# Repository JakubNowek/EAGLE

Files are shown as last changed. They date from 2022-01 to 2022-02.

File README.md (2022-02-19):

<br />
<div align="center">
  <h2 align="center">Electronics in Automation</h3>

  <p align="center">
    7-Segment Display Clock Project
    <br />
    <br />
    <a href="https://github.com/JakubNowek/EAGLE/issues">Report Bug</a>
    ·
    <a href="https://github.com/JakubNowek/EAGLE/issues">Request Feature</a>
  </p>
</div>

<!-- TABLE OF CONTENTS -->
<details>
  <summary>Table of Contents</summary>
  <ol>
    <li>
      <a href="#about-the-project">About The Project</a>
    </li>
    <li><a href="#finished-project">Finished Project</a>
    </li>
    <li><a href="#pcb-layout">PCB layout</a></li>
    <li><a href="#arduino-code">Arduino Code</a></li>
    <li><a href="#bill-of-materials">Bill of materials</a></li>
  </ol>
</details>

## About the Project
The ESP-01s module connects to NTP server and retrives information about the current date from it. Next data is forwarded towards Arduino Pro-Mini which extracts the time in hours, minutes and seconds and sends them towards 7-segments display through shift register.
Everything is powered up by a 7.5-25V power supply, the power of which is reduced to 5V by a voltage stabilizer.

## Finished Project


## PCB layout
Layout was auto generated using Altium Designer.
pcb layout

## Arduino Code
Used code for ESP module and Pro-Mini board can be found [here](projects/Serial_NTP_clock/ESP8266_with_NTP_code.ino) and [here](projects/Serial_NTP_clock/Pro_mini_code.ino).

## Bill of materials
| Qty | Value | Device |
|-----|---|---|
| 2 | | 7SEG-CA |
| 6 | | BC556A-PNP-TO92-EBC |
| 2 | 0.1u | C-EU025-025X050 |
| 6 | 100 | R-EU_0414/15 |
| 1 | 10u | C-EU025-025X050 |
| 10  | 220 | R-EU_0414/15 |
| 1 | 2k2 | R-EU_0414/15 |
| 2 | 470u/25V | CPOL-EUE5-8.5 |
| 1 | 74HC595N | 74HC595N |
| 1 | 7805T | 7805T |
| 1 | DCJ0202 | DCJ0202 |
| 1 | ESP-01 | ESP-01 |
| 1 | LD117AV | LD117AV |
| 1 | LDQ-M3604RI | LDQ-M3604RI |
| 1 | PRO-MINI | PRO-MINI |

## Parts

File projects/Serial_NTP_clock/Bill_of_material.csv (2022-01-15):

Qty | Value | Device | Package | Parts | Description | AVAILABILITY | DESCRIPTION | MF | MP | MPN | OC_FARNELL | OC_NEWARK | PACKAGE | POPULARITY | PRICE | SPICEPREFIX
2 |  | 7SEG-CA | 7SEG-13 | D1, D2 | 7-segment DISPLAY |  |  |  |  |  |  |  |  | 5
6 |  | BC556A-PNP-TO92-EBC | TO92-EBC | T1, T2, T3, T4, T5, T6 | PNP Transistror |  |  |  |  |  |  |  |  | 0
2 | 0.1u | C-EU025-025X050 | C025-025X050 | C3, C5 | CAPACITOR, European symbol |  |  |  |  |  |  |  |  | 65 |  | C
6 | 100 | R-EU_0414/15 | 0414/15 | R4, R5, R6, R7, R8, R9 | RESISTOR, European symbol |  |  |  |  |  |  |  |  | 0 |  | R
1 | 10u | C-EU025-025X050 | C025-025X050 | C4 | CAPACITOR, European symbol |  |  |  |  |  |  |  |  | 65 |  | C
10 | 220 | R-EU_0414/15 | 0414/15 | R1, R3, R10, R11, R12, R13, R14, R15, R16, R17 | RESISTOR, European symbol |  |  |  |  |  |  |  |  | 0 |  | R
1 | 2k2 | R-EU_0414/15 | 0414/15 | R2 | RESISTOR, European symbol |  |  |  |  |  |  |  |  | 0 |  | R
2 | 470u/25V | CPOL-EUE5-8.5 | E5-8,5 | C1, C2 | POLARIZED CAPACITOR, European symbol |  |  |  |  |  |  |  |  | 0 |  | C
1 | 74HC595N | 74HC595N | DIL16 | IC1 | 8-bit SHIFT REGISTER, output latch |  |  |  |  |  |  |  |  | 0
1 | 7805T | 7805T | TO220H | IC2 | Positive VOLTAGE REGULATOR
1 | DCJ0202 | DCJ0202 | DCJ0202 | J1 | DC POWER JACK |  |  |  |  |  | unknown | unknown |  | 17
1 | ESP-01 | ESP-01 | ESP-01 | ESP1 | Check prices | Not in stock | ESP-01M ESP8266 DIP Adapter series Transceiver | 802.11 b/g/n (Wi-Fi, WiFi, WLAN) Evaluation Board | AI-Thinker | ESP-01 |  |  |  | Non-Standard AI-Thinker |  | None
1 | LD117AV | LD117AV | TO220L1 | IC3 | Low drop fixed and adjustable positive voltage regulators 1 A |  |  |  |  |  |  |  |  | 0
1 | LDQ-M3604RI | LDQ-M3604RI | LDQ-M3604RI | LED1 | Check prices | In Stock | Display, Seven Segment, 9.2MM, Red | Lumex | LDQ-M3604RI |  |  |  | None |  | None
1 | PRO-MINI | PRO-MINI | PRO-MINI | U$1 | Arduion Pro Mini Clone V1.0

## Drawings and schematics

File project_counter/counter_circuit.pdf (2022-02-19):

A

A

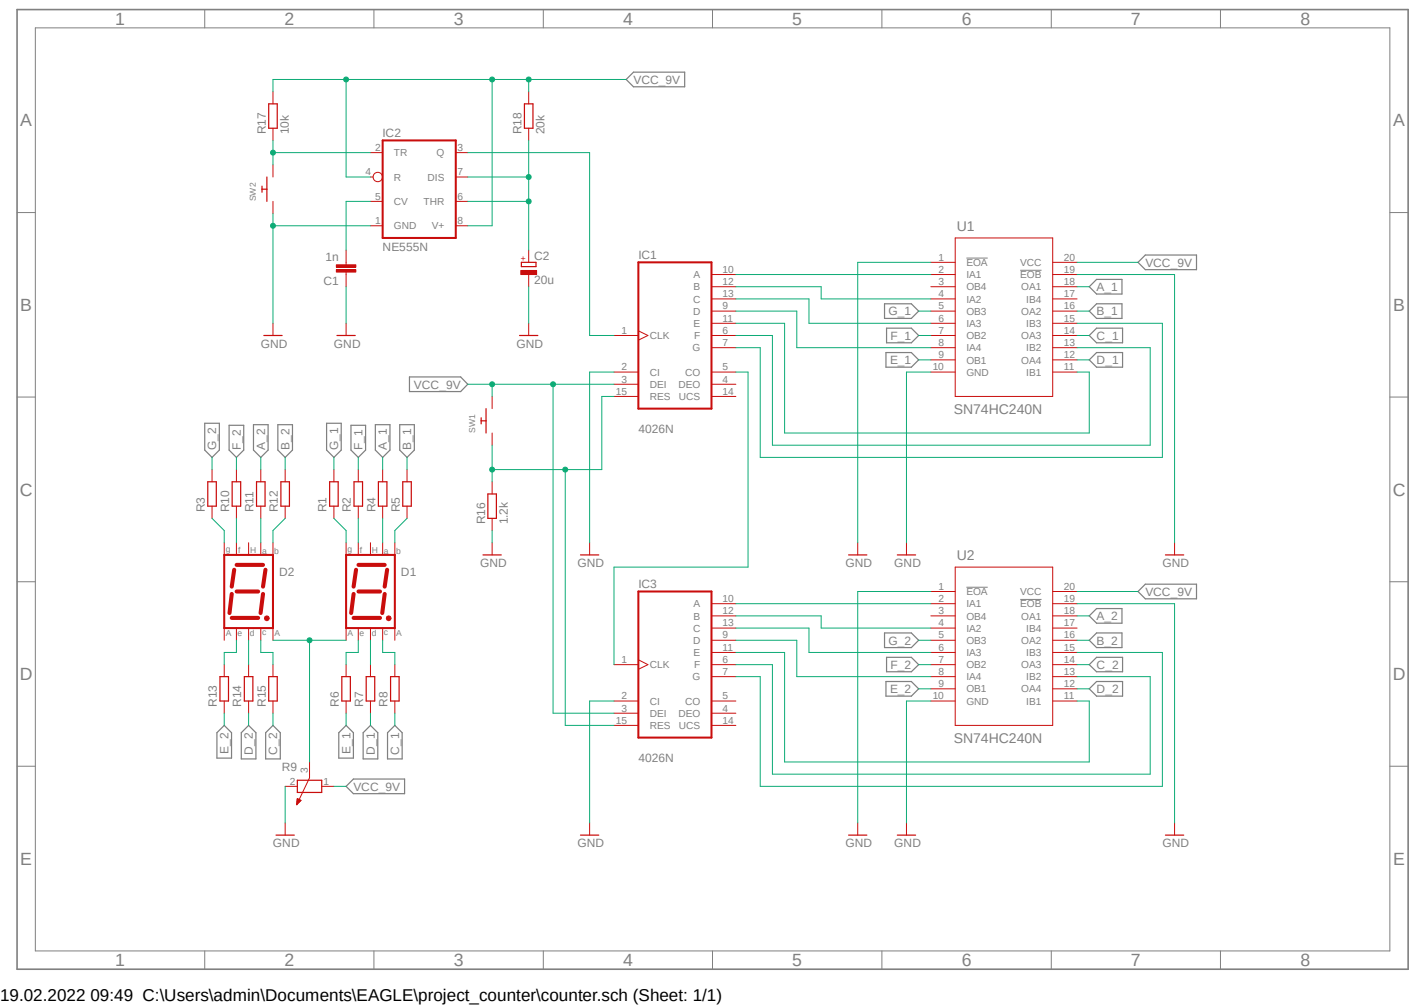
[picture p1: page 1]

19.02.2022 09:49 C:\Users\admin\Documents\EAGLE\project_counter\counter.sch (Sheet: 1/1)

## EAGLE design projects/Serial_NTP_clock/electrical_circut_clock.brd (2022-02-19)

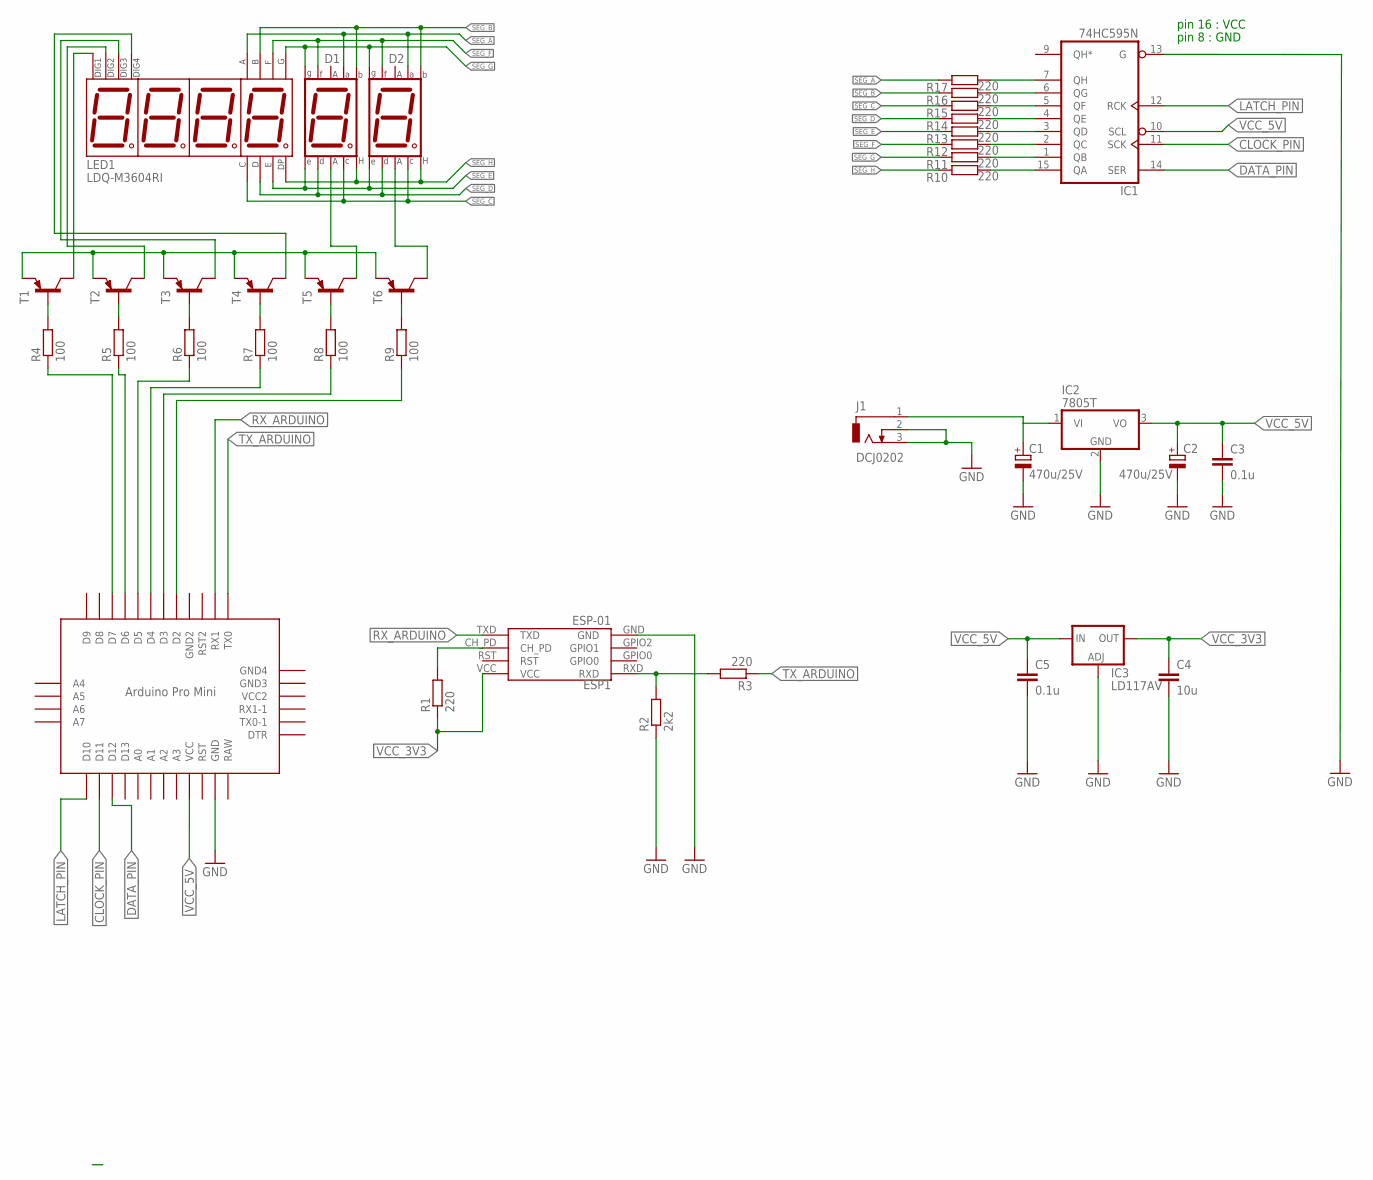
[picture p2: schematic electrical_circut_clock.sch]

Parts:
C1, C2: 470u/25V; E5-8,5
C3, C5: 0.1u; C025-025X050
C4: 10u; C025-025X050
D1, D2: 7SEG-CA; 7SEG-13
ESP1: ESP-01
IC1: 74HC595N; DIL16
IC2: 7805T; TO220H
IC3: LD117AV; TO220L1
J1: DCJ0202
LED1: LDQ-M3604RI
R1, R3, R10, R11, R12, R13, R14, R15, R16, R17: 220; 0204/7
R2: 2k2; 0204/7
R4, R5, R6, R7, R8, R9: 100; 0204/7
T1, T2, T3, T4, T5, T6: BC556A-PNP-TO92-EBC; TO92-EBC
U$1: PRO-MINI

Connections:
CLOCK_PIN: IC1.11 (SCK), U$1.D11
DATA_PIN: IC1.14 (SER), U$1.D12
GND: C1.-, C2.-, C3.2, C4.2, C5.2, ESP1.GND, IC1.8 (GND), IC1.13 (G), IC2.2 (GND), IC3.1 (ADJ), J1.2, J1.3, R2.1, U$1.GND
LATCH_PIN: IC1.12 (RCK), U$1.D10
unnamed: R4.2, T1.B
unnamed: R5.2, T2.B
unnamed: R6.2, T3.B
unnamed: R7.2, T4.B
unnamed: R8.2, T5.B
unnamed: R9.2, T6.B
unnamed: T1.E, T2.E, T3.E, T4.E, T5.E, T6.E
unnamed: LED1.9 (DIG2), T2.C
unnamed: R4.1, U$1.D7
unnamed: ESP1.CH_PD, R1.2
unnamed: IC1.15 (QA), R10.2
unnamed: IC1.1 (QB), R11.2
unnamed: IC1.2 (QC), R12.2
unnamed: IC1.3 (QD), R13.2
unnamed: IC1.4 (QE), R14.2
unnamed: IC1.5 (QF), R15.2
unnamed: IC1.6 (QG), R16.2
unnamed: IC1.7 (QH), R17.2
unnamed: LED1.12 (DIG1), T1.C
unnamed: LED1.8 (DIG3), T3.C
unnamed: LED1.6 (DIG4), T4.C
unnamed: D1.8 (CA2), T5.C
unnamed: D2.8 (CA2), T6.C
unnamed: R5.1, U$1.D6
unnamed: R6.1, U$1.D5
unnamed: R7.1, U$1.D4
unnamed: R8.1, U$1.D3
unnamed: R9.1, U$1.D2
RAW: U$1.RAW
RX_ARDUINO: ESP1.TXD, U$1.RX1
SEG_A: D1.7 (A), D2.7 (A), LED1.11 (A), R17.1
SEG_B: D1.6 (B), D2.6 (B), LED1.7 (B), R16.1
SEG_C: D1.4 (C), D2.4 (C), LED1.4 (C), R15.1
SEG_D: D1.2 (D), D2.2 (D), LED1.2 (D), R14.1
SEG_E: D1.1 (E), D2.1 (E), LED1.1 (E), R13.1
SEG_F: D1.9 (F), D2.9 (F), LED1.10 (F), R12.1
SEG_G: D1.10 (G), D2.10 (G), LED1.5 (G), R11.1
SEG_H: D1.5 (DP), D2.5 (DP), LED1.3 (DP), R10.1
TX_ARDUINO: ESP1.RXD, R2.2, R3.1, R3.2, U$1.TX0
VCC: IC1.16 (VCC)
VCC_3V3: C4.1, ESP1.VCC, IC3.2 (OUT), R1.1
VCC_5V: C2.+, C3.1, C5.1, IC1.10 (SCL), IC2.3 (VO), IC3.3 (IN), U$1.VCC
VIN_9V: C1.+, IC2.1 (VI), J1.1

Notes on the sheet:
pin 16 : VCC
pin 8 : GND

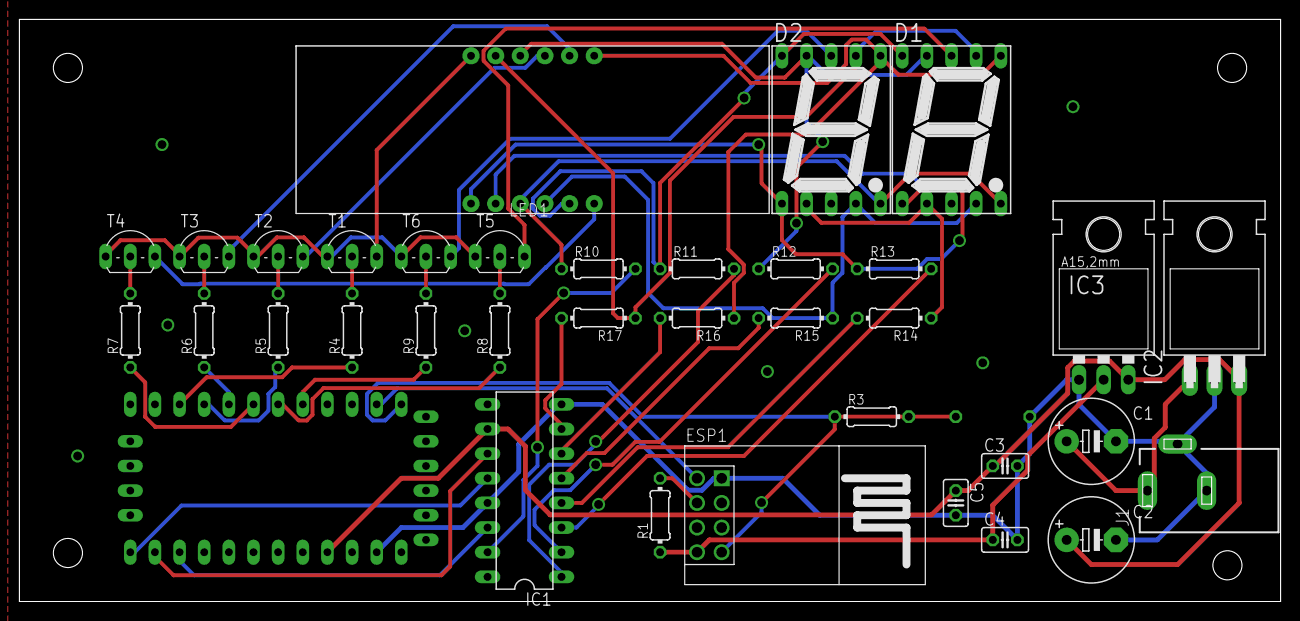
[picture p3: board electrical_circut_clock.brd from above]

Board: 2 copper layers, 130.0 x 60.0 mm, 37 parts (1 on the bottom side), 45 nets.

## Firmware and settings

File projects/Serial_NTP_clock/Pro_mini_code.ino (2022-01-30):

//Zdefiniowanie polaczenia ESP8266 do Arduino UNO
String ASCII = "ABCDEFGHIJKLMNOPQRSTUVWXYZ[\\]^_`abcdefghijklmnopqrstuvwxyz"; //alfabet ASCII
int buff; // bufor do wczytanych danych
int czas[13];//={0,1,2,3,4,5,6,7,8,9,10,11,12}; //tablica na sekundy, minuty, godzine i date
//baza do sekretnych wiadomosci
unsigned int d = B01111010, u = B01111100, p = B11001110, a = B11101110;  
// Define Connections to 74HC595
#define TIME 3  //Zmienna okreslajaca czas, po ktorym ma nastapic przelaczenie wyswietlacza 
#define INTERVAL 1000
#define HOW_LATE 1
// Zdediniowanie połączeń z 74HC595
// ST_CP pin 12
const int latchPin = 10;
// SH_CP pin 11
const int clockPin = 11;
// DS pin 14
const int dataPin = 12;


// szesnastkowy zapis segmentów wyświetlacza użytych do wyświetlenia cyfr 0,1,2,3,4,5,6,7,8,9
int numArray[16] = {0xFC, 0x60, 0xDA, 0xF2, 0x66, 0xB6, 0xBE, 0xE0, 0xFE, 0xF6};
/*piny odpowiedzialne za przelaczanie wyswietlaczy
//dig_1 = 7;
//dig_2 = 6;
//dig_3 = 5;
//dig_4 = 4;
//dig_5 = 3;
//dig_6 = 2;*/
int digArray[6] = {7,6,5,4,3,2}; 

unsigned long previousMillis = 0; //stosujemy w funkcji millis() zamiast delay(1000)
unsigned long currentMillis; 


void setup ()
{
  // Ustawienie wyjść
  pinMode(latchPin, OUTPUT);
  pinMode(clockPin, OUTPUT);
  pinMode(dataPin, OUTPUT);
  pinMode(digArray[0], OUTPUT);
  pinMode(digArray[1], OUTPUT);
  pinMode(digArray[2], OUTPUT);
  pinMode(digArray[3], OUTPUT);
  pinMode(digArray[4], OUTPUT);
  pinMode(digArray[5], OUTPUT);
  digitalWrite(digArray[0],LOW); //low zamiast high bo tu jest NPN (gdyby było 6xPNP to tu byłoby HIGH)
  digitalWrite(digArray[1],HIGH);
  digitalWrite(digArray[2],HIGH);
  digitalWrite(digArray[3],HIGH);
  digitalWrite(digArray[4],HIGH);
  digitalWrite(digArray[5],HIGH);
  for(int i=0;i<13;i++)
  czas[i] = 8;
  //inicjalizacja portu szeregowego
  Serial.begin(9600);
  delay(1000);
}

void print(int digit)
{
    // ST_CP LOW to keep LEDs from changing while reading serial data
    digitalWrite(latchPin, LOW);
    // Shift out the bits
    shiftOut(dataPin, clockPin, MSBFIRST, digit);
    // ST_CP HIGH change LEDs
    digitalWrite(latchPin, HIGH);
}

void printTime(int hours, int minutes, int seconds) // moze wypisywac czas albo date
{
  // #1
  print(~numArray[hours/10]);
  digitalWrite(digArray[0],HIGH); //zalaczenie wyswiwietlacza #1 (tu high/low na odwrot bo NPN zamiast PNP)
  delay(TIME);
  digitalWrite(digArray[0],LOW); //wylaczenie wyswietlacza #1
  // #2
  print(~(numArray[hours%10] | 0x01)); // dziesiata czesc godziny + separator
  digitalWrite(digArray[1],LOW); //zalaczenie wyswiwietlacza #2
  delay(TIME);
  digitalWrite(digArray[1],HIGH); //wylaczenie wyswietlacza #2
  // #3
  print(~numArray[minutes/10]);
  digitalWrite(digArray[2],LOW);
  delay(TIME);
  digitalWrite(digArray[2],HIGH);
  //#4
  print(~(numArray[minutes%10]| 0x01));// dziesiata czesc minuty + separator
  digitalWrite(digArray[3],LOW);
  delay(TIME);
  digitalWrite(digArray[3],HIGH);
  //#5
  print(~numArray[seconds/10]);
  digitalWrite(digArray[4],LOW);
  delay(TIME);
  digitalWrite(digArray[4],HIGH);
  //#6
  print(~numArray[seconds%10]);
  digitalWrite(digArray[5],LOW);
  delay(TIME);
  digitalWrite(digArray[5],HIGH);
  
}

void printTimeLong(/*int s1, int s2, int m1, int m2,int h1, int h2*/ ) // moze wypisywac czas albo date
{
  /*----------sekundy-------------*/
  //#5 - czesci dziesiate sekund
  print(~numArray[czas[0]]);
  digitalWrite(digArray[4],LOW);
  delay(TIME);
  digitalWrite(digArray[4],HIGH);
  //#6 - jednosci sekund
  print(~numArray[czas[1]]);
  digitalWrite(digArray[5],LOW);
  delay(TIME);
  digitalWrite(digArray[5],HIGH);
  /*----------minuty-------------*/
    // #3 - czesci dziesiate minut
  print(~numArray[czas[2]]);
  digitalWrite(digArray[2],LOW);
  delay(TIME);
  digitalWrite(digArray[2],HIGH);
  //#4 - jednosci minut
  print(~(numArray[czas[3]]| 0x01));// dziesiata czesc minuty + separator
  digitalWrite(digArray[3],LOW);
  delay(TIME);
  digitalWrite(digArray[3],HIGH);
  /*----------godziny-------------*/
  // #1 - dziesiate czesci godzin
  print(~numArray[czas[4]]);
  digitalWrite(digArray[0],HIGH); //zalaczenie wyswiwietlacza #1 (tu high/low na odwrot bo NPN zamiast PNP)
  delay(TIME);
  digitalWrite(digArray[0],LOW); //wylaczenie wyswietlacza #1
  // #2 - jednosci godzin
  print(~(numArray[czas[5]] | 0x01)); // jednosci godzin + separator (kropka)
  digitalWrite(digArray[1],LOW); //zalaczenie wyswiwietlacza #2
  delay(TIME);
  digitalWrite(digArray[1],HIGH); //wylaczenie wyswietlacza #2
}

void printMessage(int a, int b, int c, int d, int e, int f){

  // #1
  print(~a);
  digitalWrite(digArray[0],HIGH); //zalaczenie wyswiwietlacza #1 (tu high/low na odwrot bo NPN zamiast PNP)
  delay(TIME);
  digitalWrite(digArray[0],LOW); //wylaczenie wyswietlacza #1
  // #2
  print(~b); // dziesiata czesc godziny + separator
  digitalWrite(digArray[1],LOW); //zalaczenie wyswiwietlacza #2
  delay(TIME);
  digitalWrite(digArray[1],HIGH); //wylaczenie wyswietlacza #2
  // #3
  print(~c);
  digitalWrite(digArray[2],LOW);
  delay(TIME);
  digitalWrite(digArray[2],HIGH);
  //#4
  print(~d | 0x01);// dziesiata czesc minuty + separator
  digitalWrite(digArray[3],LOW);
  delay(TIME);
  digitalWrite(digArray[3],HIGH);
  //#5
  print(~e);
  digitalWrite(digArray[4],LOW);
  delay(TIME);
  digitalWrite(digArray[4],HIGH);
  //#6
  print(~f);
  digitalWrite(digArray[5],LOW);
  delay(TIME);
  digitalWrite(digArray[5],HIGH);
}

void serialRead()
{
  int indeks = 0;
      while(Serial.available()>0) //czytanie calej informacji o aktualnej dacie
    {
      buff = Serial.read(); 
      if(buff<48 || buff>57)
      Serial.print(ASCII[buff-65]);
      else {
            czas[indeks] = (buff-48);
            Serial.print(buff - 48);
            //if(indeks<6)
            indeks++;
           }
    }
  Serial.print('\n');
}


void loop()
{
  currentMillis = millis();
  
  if(currentMillis - previousMillis >= INTERVAL)
  {
    serialRead(); 
    previousMillis = currentMillis;
  }
  if(czas[4] == 0 && czas[5] == 0 && czas[2] == 0 && czas[3] == 0) //wyswietlanie wiadomosci o polnocy
  printMessage(a,p,u,d,numArray[czas[0]], numArray[czas[1]]);
  else{  printTimeLong();  }
}

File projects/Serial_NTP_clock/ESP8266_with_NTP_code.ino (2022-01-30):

/*
  This is an example file for using the time function in ESP8266 or ESP32 tu get NTP time
  It offers two functions:
  - getNTPtime(struct tm * info, uint32_t ms) where info is a structure which contains time
  information and ms is the time the service waits till it gets a response from NTP.
  Each time you cann this function it calls NTP over the net.
  If you do not want to call an NTP service every second, you can use
  - getTimeReducedTraffic(int ms) where ms is the the time between two physical NTP server calls. Betwwn these calls,
  the time structure is updated with the (inaccurate) timer. If you call NTP every few minutes you should be ok
  The time structure is called tm and has teh following values:
  Definition of struct tm:
  Member  Type  Meaning Range
  tm_sec  int seconds after the minute  0-61*
  tm_min  int minutes after the hour  0-59
  tm_hour int hours since midnight  0-23
  tm_mday int day of the month  1-31
  tm_mon  int months since January  0-11
  tm_year int years since 1900
  tm_wday int days since Sunday 0-6
  tm_yday int days since January 1  0-365
  tm_isdst  int Daylight Saving Time flag
  because the values are somhow akwardly defined, I introduce a function makeHumanreadable() where all values are adjusted according normal numbering.
  e.g. January is month 1 and not 0 And Sunday or monday is weekday 1 not 0 (according definition of MONDAYFIRST)
  Showtime is an example on how you can use the time in your sketch
  The functions are inspired by work of G6EJD ( https://www.youtube.com/channel/UCgtlqH_lkMdIa4jZLItcsTg ),
  and code of mr Andreas Spiess (https://www.youtube.com/watch?v=r2UAmBLBBRM). Many thanks.
*/

#ifdef ESP8266
#include <ESP8266WiFi.h>
#include <ESP8266WiFiMulti.h>
#else
#include <WiFi.h>
#endif
#include <time.h>
// #include <credentials.h>
ESP8266WiFiMulti wifiMulti; //  MOD
const uint32_t connectTimeoutMs = 6000; //MOD
boolean connectioWasAlive = true;

#ifdef CREDENTIALS
const char* ssid = mySSID;
const char* password = myPASSWORD;
#else
const char* ssid_1 = "Your_WIFI_name";
const char* password_1 = "here_put_your_passwd";

const char* ssid_2 = "Your_neighbour_WIFI_name";
const char* password_2 = "here_put_your_neighbour's_passwd";

#endif

const char* NTP_SERVER = "ch.pool.ntp.org";
const char* TZ_INFO    = "CET-1CEST-2,M3.5.0/02:00:00,M10.5.0/03:00:00";  // enter your time zone (https://remotemonitoringsystems.ca/time-zone-abbreviations.php)

tm timeinfo;
time_t now;
long unsigned lastNTPtime;
unsigned long lastEntryTime;
int timer;

void setup() {
  Serial.begin(/*115200*/9600);
  Serial.println("\n\nNTP_Time_Test\n");
  //WiFi.begin(ssid, password); //MOD
  WiFi.mode(WIFI_STA); //MOD
  wifiMulti.addAP("Straż Miejska 47853","12345678" ); //MOD
  wifiMulti.addAP(ssid_1,password_1 ); //MOD
  wifiMulti.addAP(ssid_2,password_2 ); //MOD
  int counter = 0;
  while (wifiMulti.run(connectTimeoutMs) != WL_CONNECTED) { //MOD
    boolean connectioWasAlive = false;
    delay(200);
    if (++counter > 100) ESP.restart();
    Serial.print ( "." );
  }
  Serial.println("\n\nWiFi_connected\n\n");
  Serial.printf("connected to %s\n",WiFi.SSID().c_str());
  configTime(0, 0, NTP_SERVER);
  // See https://github.com/nayarsystems/posix_tz_db/blob/master/zones.csv for Timezone codes for your region
  setenv("TZ", TZ_INFO, 1);

  if (getNTPtime(10)) {  // wait up to 10sec to sync
  } else {
    Serial.println("Time_not_set");
     ESP.restart();
  }
  showTime(timeinfo);
  lastNTPtime = time(&now);
  lastEntryTime = millis();
}

void loop() {
  getNTPtime(10);
  showTime(timeinfo);
  delay(1000);
}

bool getNTPtime(int sec) {

  {
    uint32_t start = millis();
    do {
      time(&now);
      localtime_r(&now, &timeinfo);
      //Serial.print(".");
      delay(10);
    } while (((millis() - start) <= (1000 * sec)) && (timeinfo.tm_year < (2016 - 1900)));
    if (timeinfo.tm_year <= (2016 - 1900)) return false;  // the NTP call was not successful
    char time_output[30];
    strftime(time_output, 30, "%a  %d-%m-%y %T", localtime(&now+1)); //MOD (+1)
  }
  return true;
}
// Data is send through serial port in form "s(seconds)m(minutes)h(hours)D(day_of_the_week)M(month)Y(year)R(number_of_the_day_of_the_week)"
void showTime(tm localTime) {
  Serial.print('s');
  if(localTime.tm_sec/10 == 0)
  Serial.print('0');
  Serial.print(localTime.tm_sec);
  //Serial.print(':');
  Serial.print('m');
  if(localTime.tm_min/10 == 0)
  Serial.print('0');
  Serial.print(localTime.tm_min);
  //Serial.print(':');
  Serial.print('h');
  if(localTime.tm_hour/10 == 0)
  Serial.print('0');
  Serial.print(localTime.tm_hour);
  //Serial.print('-');
  Serial.print('D');
  if(localTime.tm_mday/10 == 0)
  Serial.print('0');
  Serial.print(localTime.tm_mday);
  //Serial.print('/');
  Serial.print('M');
  if((localTime.tm_mon+1)/10 == 0)
  Serial.print('0');
  Serial.print(localTime.tm_mon + 1);
  //Serial.print('/');
  Serial.print('Y');
  if(localTime.tm_year/10 == 0)
  Serial.print('0');
  Serial.print(localTime.tm_year - 100);
  Serial.print('R');
  if (localTime.tm_wday == 0)   Serial.println(7);
  else Serial.println(localTime.tm_wday);
}

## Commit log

2022-01-03 new arduino uno symbol
    [pierwszy_schemat_dobrow.sch]
2022-01-03 added labels
    [pierwszy_schemat_dobrow.sch]
2022-01-03 labels of 7-seg rearanged
    [pierwszy_schemat_dobrow.sch]
2022-01-03 completed lm7805 schematics
    [pierwszy_schemat_dobrow.sch]
2022-01-04 added 3v3voltage regulator and rearanged
    [pierwszy_schemat_dobrow.sch]
2022-01-04 final rearangement?
    nie wiem czy nie zmienić tego arduino na coś normalnego i co z tymi pinami zasilania rejestru przesuwnego?
    [pierwszy_schemat_dobrow.sch]
2022-01-05 changed arduino to pro mini
    [pierwszy_schemat_dobrow.sch]
2022-01-12 repaired gnd connection
    [pierwszy_schemat_dobrow.sch]
2022-01-12 repair v2
    [pierwszy_schemat_dobrow.sch]
2022-01-13 Added board with mounting holes and started designing power module
    [pierwszy_schemat_dobrow.brd]
2022-01-13 Done power section
    [pierwszy_schemat_dobrow.brd]
2022-01-13 Added ESP-01 module
    [pierwszy_schemat_dobrow.brd]
2022-01-13 Connected display module
    [pierwszy_schemat_dobrow.brd]
2022-01-14 Completed first revision of pcb design
    [pierwszy_schemat_dobrow.brd]
2022-01-14 Fixed overlapping circuit
    [pierwszy_schemat_dobrow.brd]
2022-01-15 Added power jack
    [pierwszy_schemat_dobrow.brd, pierwszy_schemat_dobrow.sch]
2022-01-15 moved resistors for better thermal flow
    [pierwszy_schemat_dobrow.brd]
2022-01-26 changed resistors type
    [pierwszy_schemat_dobrow.sch]
2022-01-26 Second revision of pcb layout
    [pierwszy_schemat_dobrow.brd]
2022-01-30 Added code for arduino and esp
2022-01-30 renamed arduino code
2022-01-30 renamed pcb file
    [PCB_board_clock.brd]
2022-01-30 created clock folder
    [Bill_of_material.csv, PCB_board_clock.brd, electrical_circut_clock.sch]
2022-01-30 Grounded plate, relocated module of scheme and added more vias
    [PCB_board_clock.brd, electrical_circut_clock.sch]
2022-01-31 fixed consistency problems
    [electrical_circut_clock.brd, electrical_circut_clock.sch]
2022-02-19 Added counter circuit
    [counter.sch]
2022-02-19 circuit pdf update
